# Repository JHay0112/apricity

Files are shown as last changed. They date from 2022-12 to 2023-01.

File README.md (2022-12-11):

# Apricity - Sunrise Alarm

Apricity is my second attempt at designing and building a sunrise alarm. 

The first attempt (https://jordanhay.com/blog/2021/08/sunrise-alarm) was based upon a development board and a 3D printed enclosure. Apricity will improve upon this design with a custom PCB and firmware.

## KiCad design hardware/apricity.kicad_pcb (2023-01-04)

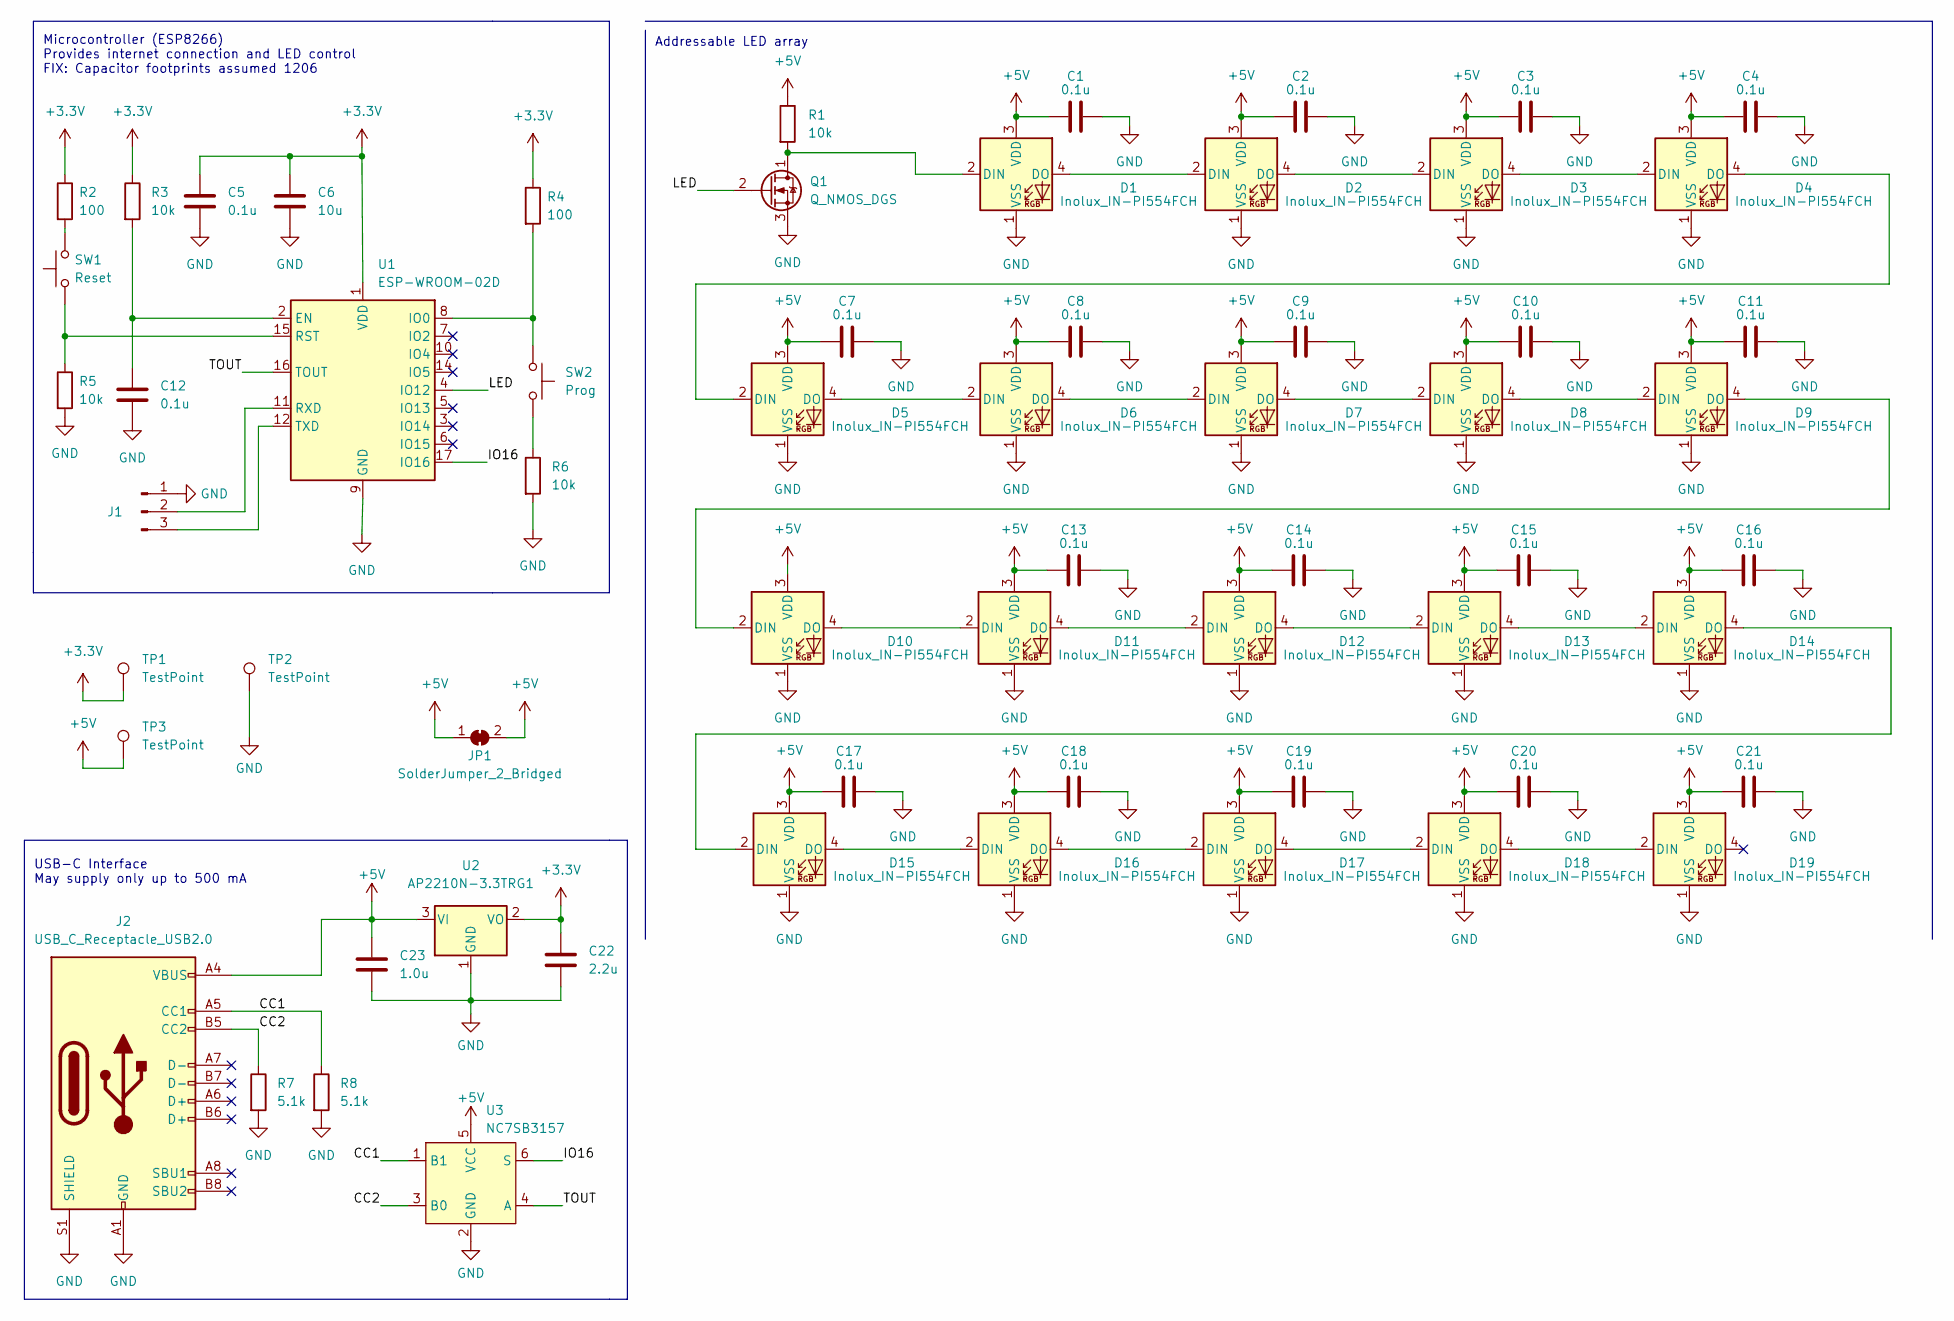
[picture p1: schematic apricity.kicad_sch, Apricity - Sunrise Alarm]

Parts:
C1, C2, C3, C4, C5, C7, C8, C9, C10, C11, C12, C13, C14, C15, C16, C17, C18, C19, C20, C21: 0.1u; C_1206_3216Metric_Pad1.33x1.80mm_HandSolder
C6: 10u; C_1206_3216Metric_Pad1.33x1.80mm_HandSolder
C22: 2.2u; C_1206_3216Metric_Pad1.33x1.80mm_HandSolder
C23: 1.0u; C_1206_3216Metric_Pad1.33x1.80mm_HandSolder
D1, D2, D3, D4, D5, D6, D7, D8, D9, D10, D11, D12, D13, D14, D15, D16, D17, D18, D19: Inolux_IN-PI554FCH; LED_Inolux_IN-PI554FCH_PLCC4_5.0x5.0mm_P3.2mm
J1: Conn_01x03_Male; PinHeader_1x03_P2.54mm_Horizontal
J2: USB_C_Receptacle_USB2.0; USB_C_Receptacle_Palconn_UTC16-G
JP1: SolderJumper_2_Bridged; R_0805_2012Metric_Pad1.20x1.40mm_HandSolder
Q1: Q_NMOS_DGS; TSOT-23_HandSoldering
R1, R3, R5, R6: 10k; R_0805_2012Metric_Pad1.20x1.40mm_HandSolder
R2, R4: 100; R_0805_2012Metric_Pad1.20x1.40mm_HandSolder
R7, R8: 5.1k; R_0805_2012Metric_Pad1.20x1.40mm_HandSolder
SW1: Reset; SW_SPST_CK_RS282G05A3
SW2: Prog; SW_SPST_CK_RS282G05A3
TP1, TP2, TP3: TestPoint; TestPoint_Pad_D1.0mm
U1: ESP-WROOM-02D; ESP-WROOM-02
U2: AP2210N-3.3TRG1; SOT-23_Handsoldering
U3: NC7SB3157; SOT-363_SC-70-6_Handsoldering

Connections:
+3.3V: C5.1, C6.1, C22.1, R2.1, R3.1, R4.1, TP1.1, U1.1 (VDD), U2.2 (VO)
+5V: C1.1, C2.1, C3.1, C4.1, C7.1, C8.1, C9.1, C10.1, C11.1, C13.1, C14.1, C15.1, C16.1, C17.1, C18.1, C19.1, C20.1, C21.1, C23.1, D1.3 (VDD), D2.3 (VDD), D3.3 (VDD), D4.3 (VDD), D5.3 (VDD), D6.3 (VDD), D7.3 (VDD), D8.3 (VDD), D9.3 (VDD), D10.3 (VDD), D11.3 (VDD), D12.3 (VDD), D13.3 (VDD), D14.3 (VDD), D15.3 (VDD), D16.3 (VDD), D17.3 (VDD), D18.3 (VDD), D19.3 (VDD), J2.A4 (VBUS), J2.A9 (VBUS), J2.B4 (VBUS), J2.B9 (VBUS), JP1.1 (A), JP1.2 (B), R1.1, TP3.1, U2.3 (VI), U3.5 (VCC)
/CC1: J2.A5 (CC1), R8.1, U3.1 (B1)
/CC2: J2.B5 (CC2), R7.1, U3.3 (B0)
/IO16: U1.17 (IO16), U3.6 (S)
/LED: Q1.2 (G), U1.4 (IO12)
/TOUT: U1.16 (TOUT), U3.4 (A)
GND: C1.2, C2.2, C3.2, C4.2, C5.2, C6.2, C7.2, C8.2, C9.2, C10.2, C11.2, C12.2, C13.2, C14.2, C15.2, C16.2, C17.2, C18.2, C19.2, C20.2, C21.2, C22.2, C23.2, D1.1 (VSS), D2.1 (VSS), D3.1 (VSS), D4.1 (VSS), D5.1 (VSS), D6.1 (VSS), D7.1 (VSS), D8.1 (VSS), D9.1 (VSS), D10.1 (VSS), D11.1 (VSS), D12.1 (VSS), D13.1 (VSS), D14.1 (VSS), D15.1 (VSS), D16.1 (VSS), D17.1 (VSS), D18.1 (VSS), D19.1 (VSS), J1.1, J2.A1 (GND), J2.A12 (GND), J2.B1 (GND), J2.B12 (GND), J2.S1 (SHIELD), Q1.3 (S), R5.2, R6.2, R7.2, R8.2, TP2.1, U1.9 (GND), U1.13 (GND), U1.18 (GND), U1.19 (GND), U2.1 (GND), U3.2 (GND)
unnamed: C12.1, R3.2, U1.2 (EN)
unnamed: D1.2 (DIN), Q1.1 (D), R1.2
unnamed: D1.4 (DO), D2.2 (DIN)
unnamed: D2.4 (DO), D3.2 (DIN)
unnamed: D3.4 (DO), D4.2 (DIN)
unnamed: D4.4 (DO), D5.2 (DIN)
unnamed: D5.4 (DO), D6.2 (DIN)
unnamed: D6.4 (DO), D7.2 (DIN)
unnamed: D7.4 (DO), D8.2 (DIN)
unnamed: D8.4 (DO), D9.2 (DIN)
unnamed: D9.4 (DO), D10.2 (DIN)
unnamed: D10.4 (DO), D11.2 (DIN)
unnamed: D11.4 (DO), D12.2 (DIN)
unnamed: D12.4 (DO), D13.2 (DIN)
unnamed: D13.4 (DO), D14.2 (DIN)
unnamed: D14.4 (DO), D15.2 (DIN)
unnamed: D15.4 (DO), D16.2 (DIN)
unnamed: D16.4 (DO), D17.2 (DIN)
unnamed: D17.4 (DO), D18.2 (DIN)
unnamed: D18.4 (DO), D19.2 (DIN)
unnamed: J1.2, U1.11 (RXD)
unnamed: J1.3, U1.12 (TXD)
unnamed: R2.2, SW1.2
unnamed: R4.2, SW2.1, U1.8 (IO0)
unnamed: R5.1, SW1.1, U1.15 (RST)
unnamed: R6.1, SW2.2

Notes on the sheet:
Addressable LED array
USB-C Interface May supply only up to 500 mA
Microcontroller (ESP8266) Provides internet connection and LED control FIX: Capacitor footprints assumed 1206

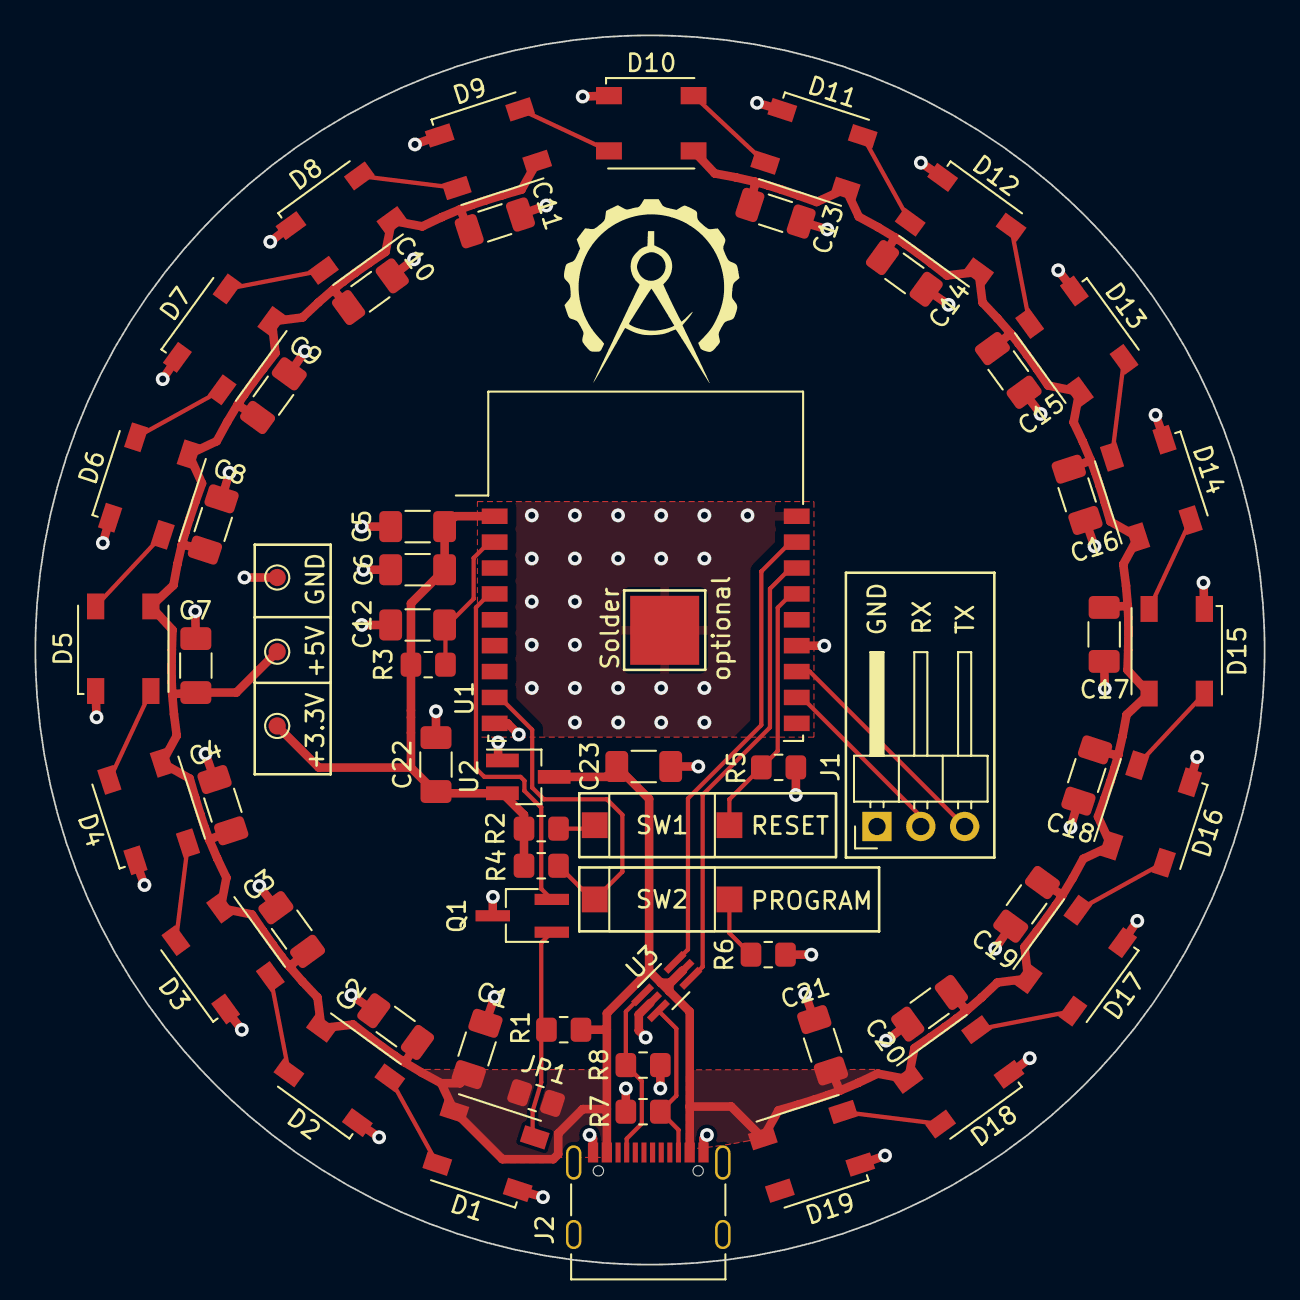
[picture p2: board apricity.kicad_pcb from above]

Board: 2 copper layers, 71.2 x 71.2 mm, 62 parts (0 on the bottom side), 34 nets.

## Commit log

2022-12-11 Setup hardware and readme
    [apricity.kicad_pcb, apricity.kicad_sch]
2022-12-14 Prototype ESP8266-based version
    [apricity.kicad_pcb, apricity.kicad_sch]
2022-12-24 lay down prototype circular array
    [apricity.kicad_pcb, apricity.kicad_sch]
2022-12-24 Perform component relink and add attribution
    [apricity.kicad_pcb]
2022-12-24 Experiment with power plane
    [apricity.kicad_pcb]
2022-12-24 Refine keepouts for power plane
    [apricity.kicad_pcb]
2022-12-27 fix power plane and add room for components
    [apricity.kicad_pcb]
2022-12-27 Annotate schematic and add power components
    [apricity.kicad_pcb, apricity.kicad_sch]
2022-12-27 layout power components on pcb
    [apricity.kicad_pcb, apricity.kicad_sch]
2022-12-27 Play with power planes
    [apricity.kicad_pcb, apricity.kicad_sch]
2022-12-28 re-arrange power components
    [apricity.kicad_pcb]
2022-12-28 remove vias from under pads
    [apricity.kicad_pcb]
2022-12-28 reintroduce ground plane below controller
    [apricity.kicad_pcb]
2022-12-28 circular power plane cutout
    [apricity.kicad_pcb]
2022-12-28 remove led vias from pads
    [apricity.kicad_pcb, apricity.kicad_sch]
2022-12-28 reduce power 'trace' width
    [apricity.kicad_pcb]
2022-12-28 remove loops
    [apricity.kicad_pcb]
2022-12-28 use jumper to connect power trace
    [apricity.kicad_pcb, apricity.kicad_sch]
2022-12-28 fix routing issues with jumper
    [apricity.kicad_pcb, apricity.kicad_sch]
2022-12-29 flesh out power regulation
    [apricity.kicad_pcb, apricity.kicad_sch]
2022-12-29 refine power as per esp datasheet
    [apricity.kicad_pcb, apricity.kicad_sch]
2022-12-29 add peripherals for programming
    [apricity.kicad_pcb, apricity.kicad_sch]
2022-12-29 add boot mode in schematic
    [apricity.kicad_sch]
2022-12-29 add logo on back of pcb
    [apricity.kicad_pcb]
2022-12-29 add buttons for program and reset
    [apricity.kicad_pcb, apricity.kicad_sch]
2022-12-29 rearrange for silkscreen consistency
    [apricity.kicad_pcb]
2022-12-29 switch to horizontal programmer
    [apricity.kicad_pcb, apricity.kicad_sch]
2022-12-29 fix drc errors
    [apricity.kicad_pcb]
2022-12-29 improve rx/tx symmetry
    [apricity.kicad_pcb]
2022-12-29 capitalize button labels
    [apricity.kicad_pcb]
2022-12-29 replace zones with traces
    [apricity.kicad_pcb]
2022-12-29 add capacitors for LEDs
    [apricity.kicad_pcb, apricity.kicad_sch]
2022-12-29 add back in capacitor for D1
    [apricity.kicad_pcb, apricity.kicad_sch]
2022-12-31 add power test points
    [apricity.kicad_pcb, apricity.kicad_sch]
2023-01-01 tweak test point positions
    [apricity.kicad_pcb]
2023-01-01 make room for usb c controller
    [apricity.kicad_pcb, apricity.kicad_sch]
2023-01-03 add analogue switch for checking current supply
    [apricity.kicad_pcb, apricity.kicad_sch]
2023-01-03 tweak silkscreen and connector placement
    [apricity.kicad_pcb]
2023-01-03 tweak led power planes
    [apricity.kicad_pcb]
2023-01-03 tweak pads again, add thermal reliefs where useful
    [apricity.kicad_pcb]
2023-01-04 add placeholder logic level shifting
    [apricity.kicad_pcb, apricity.kicad_sch]
